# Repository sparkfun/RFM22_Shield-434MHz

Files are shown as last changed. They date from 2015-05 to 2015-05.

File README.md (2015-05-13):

SparkFun RFM22 Shield - 434MHz
========================================

SparkFun RFM22 Shield - 434MHz

[*SparkFun RFM22 Shield - 434MHz (DEV-11018)*](https://www.sparkfun.com/products/11018)

The RFM22 Shield connects the RFM22 module to the appropriate lines on the Arduino. 
By using the RF22 Library, you can send and receive messages via standard 4-wire SPI. 
The library includes command structures for setting up anything from simple non-addressed point-to-point communication to fully addressed networks of clients and routers. 
The shield also provides a through-hole antenna connection for hooking up a basic wire antenna.

Repository Contents
-------------------

* **/Firmware** - Example code 
* **/Hardware** - Eagle design files (.brd, .sch)
* **/Libraries** - Libraries for use with the <PRODUCT NAME>
* **/Production** - Production panel files (.brd)

Documentation
--------------
* **[Library](https://github.com/sparkfun/SparkFun_RadioHead_Arduino_Library)** - Arduino library for the RFM22 Shield.
* **[Hookup Guide](https://www.sparkfun.com/tutorials/381)** - Basic hookup guide for the RFM22 Shield.
* **[SparkFun Fritzing repo](https://github.com/sparkfun/Fritzing_Parts)** - Fritzing diagrams for SparkFun products.
* **[SparkFun 3D Model repo](https://github.com/sparkfun/3D_Models)** - 3D models of SparkFun products. 

License Information
-------------------
This product is _**open source**_! 

The **hardware** is released under [Creative Commons ShareAlike 4.0 International](https://creativecommons.org/licenses/by-sa/4.0/).

Please use, reuse, and modify these files as you see fit. Please maintain attribution to SparkFun Electronics and release anything derivative under the same license.

Distributed as-is; no warranty is given.

- Your friends at SparkFun.

_The library is the SparkFun fork of the RadioHead library by Mike McCauley. The original library can be found here: http://www.airspayce.com/mikem/arduino/RadioHead/_

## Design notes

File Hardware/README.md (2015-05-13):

SparkFun <PRODUCT NAME> Design Files
=====================================

The .sch and .brd files hare are Eagle CAD schematic and PCB design files from SparkFun Electronics.
A freeware version of Eagle can be found [here](http://www.cadsoftusa.com/download-eagle/freeware/). 

License
---------
This product is open source! 
The hardware is released under [Creative Commons ShareAlike 4.0 International](https://creativecommons.org/licenses/by-sa/4.0/).

Please use, reuse, and modify these files as you see fit. Please maintain attribution to SparkFun Electronics and release anything derivative under the same license.

Distributed as-is; no warranty is given.

- Your friends at SparkFun.

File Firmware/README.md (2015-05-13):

SparkFun RFM22 Shield Firmware
===================================

* **Receive_Example** - Arduino examples for receiving
* **Transmit_Example** - Arduino examples for transmitting

Firmware Notes:
------------------
This code was used to  test communication between two RFM22 modules. WinAVR (AVRDude) was used to compile and write the code.  Makefiles are set up for serial programming - check out this tutorial for more info: http://www.sparkfun.com/commerce/tutorial_info.php?tutorials_id=142.

In my testing, I used two 3.3V Arduino Pro's (ATmega328), one programmed with the Receive code and one with the Transmit. Data is transmitted in 17-byte packets (16 data, 1 checksum). All of the configuration fuctions were derived from the examples posted on HopeRF's product page:
Transmit Demo: http://www.hoperf.com/upfile/RFM22_transmit_DEMO.pdf
Receive Demo: http://www.hoperf.com/upfile/RFM22_receive_DEMO.pdf

In testing, with a 17cm wire attached to the ANT pin, I got the modules to transmit about 150ft away from eachother, down a hallway. YMMV. I'd love to hear if you got it further!

There are a number of ways to configure and use these modules, and this example is by no means the best or only way to do so. I encourage you to try fiddling with the settings to tune the RFM22 for best operation with your project.

All this code is released under the Creative Commons Share-alike v3.0 license. Feel free to use it commercially or otherwise. If you have any adjustments to make to the code, I'd love to hear about them! Drop me an email (jim@sparkfun.com).

Cheers!
-Jim

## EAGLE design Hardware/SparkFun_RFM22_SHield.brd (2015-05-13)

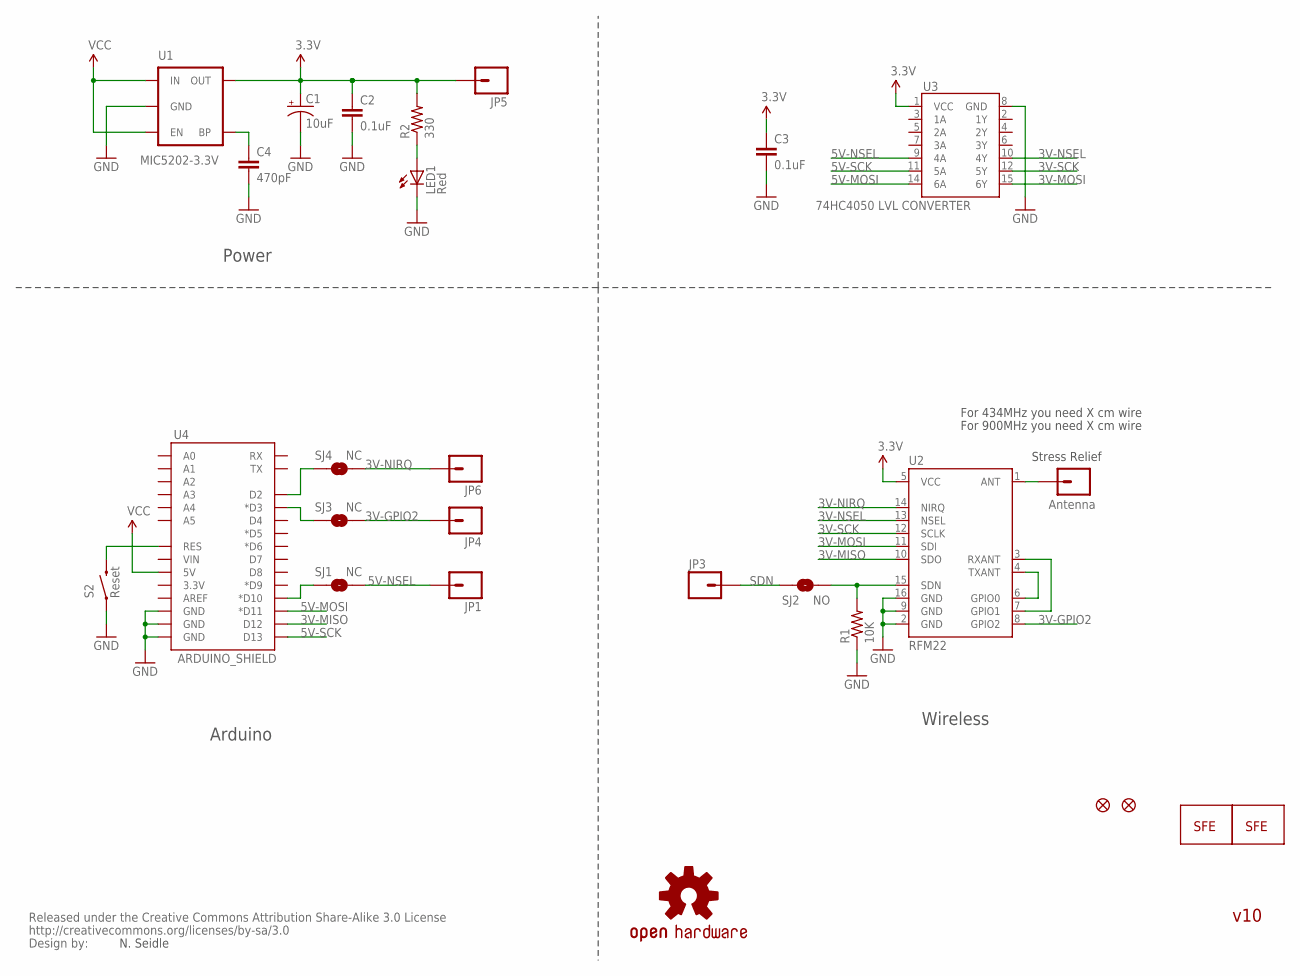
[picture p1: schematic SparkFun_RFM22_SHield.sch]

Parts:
C1: 10uF; EIA3216
C2, C3: 0.1uF; 0402-CAP
C4: 470pF; 0402-CAP
JP1, JP3, JP4, JP5, JP6: M01PTH; 1X01
JP2: Antenna; 1X01
JP7, JP8: FIDUCIALUFIDUCIAL; MICRO-FIDUCIAL
LED1: Red; LED-0603
R1: 10K; 0402-RES
R2: 330; 0402-RES
S2: Reset; TACTILE_SWITCH_SMD
SJ1, SJ3, SJ4: NC; SJ_2S-TRACE
SJ2: NO; SJ_2S-NO
U1: MIC5202-3.3V; SOT23-5
U2: RFM22; RFM22-XXX-S2
U3: 74HC4050 LVL CONVERTER; SO016
U4: ARDUINO_SHIELD; DUEMILANOVE_SHIELD_NOHOLES
U$1: OSHW-LOGOS; OSHW-LOGO-S
U$3: CREATIVE_COMMONS
U$7, U$8: LOGO-SFENEW; SFE-NEW-WEBLOGO

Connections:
3.3V: C1.A (+), C2.1, C3.1, JP5.1, R2.2, U1.5 (OUT), U2.5 (VCC), U3.1 (VCC)
3V-GPIO2: JP4.1, SJ3.2, U2.8 (GPIO2)
3V-MISO: U2.10 (SDO), U4.D12
3V-MOSI: U2.11 (SDI), U3.15 (6Y)
3V-NIRQ: JP6.1, SJ4.2, U2.14 (NIRQ)
3V-NSEL: U2.13 (NSEL), U3.10 (4Y)
3V-SCK: U2.12 (SCLK), U3.12 (5Y)
5V-MOSI: U3.14 (6A), U4.D11 (*D11)
5V-NSEL: JP1.1, SJ1.2, U3.9 (4A)
5V-SCK: U3.11 (5A), U4.D13
ARST: S2.3 (2), U4.RES
GND: C1.C (-), C2.2, C3.2, C4.2, LED1.C, R1.1, S2.1, U1.2 (GND), U2.2 (GND), U2.9 (GND), U2.16 (GND), U3.8 (GND), U4.GND@0 (GND), U4.GND@1 (GND), U4.GND@2 (GND)
unnamed: JP2.1, U2.1 (ANT)
unnamed: SJ1.1, U4.D10 (*D10)
unnamed: U2.4 (TXANT), U2.6 (GPIO0)
unnamed: U2.3 (RXANT), U2.7 (GPIO1)
unnamed: SJ3.1, U4.D3 (*D3)
unnamed: LED1.A, R2.1
unnamed: SJ4.1, U4.D2
unnamed: C4.1, U1.4 (BP)
SDN: JP3.1, SJ2.1
SDN2: R1.2, SJ2.2, U2.15 (SDN)
VCC: U1.1 (IN), U1.3 (EN), U4.5V

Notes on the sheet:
N. Seidle
Power
Arduino
Stress Relief
For 434MHz you need X cm wire
For 900MHz you need X cm wire
Wireless
v10

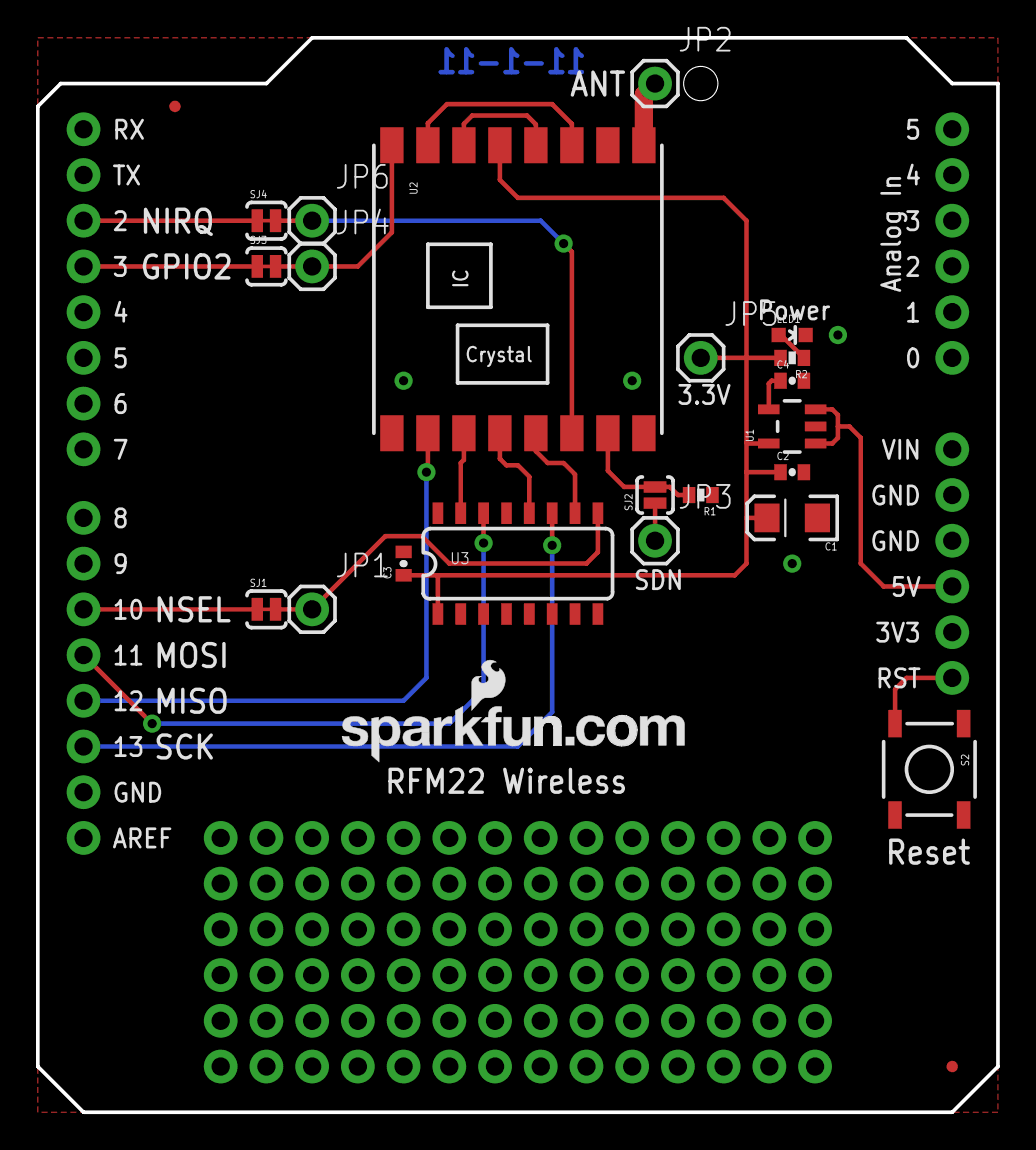
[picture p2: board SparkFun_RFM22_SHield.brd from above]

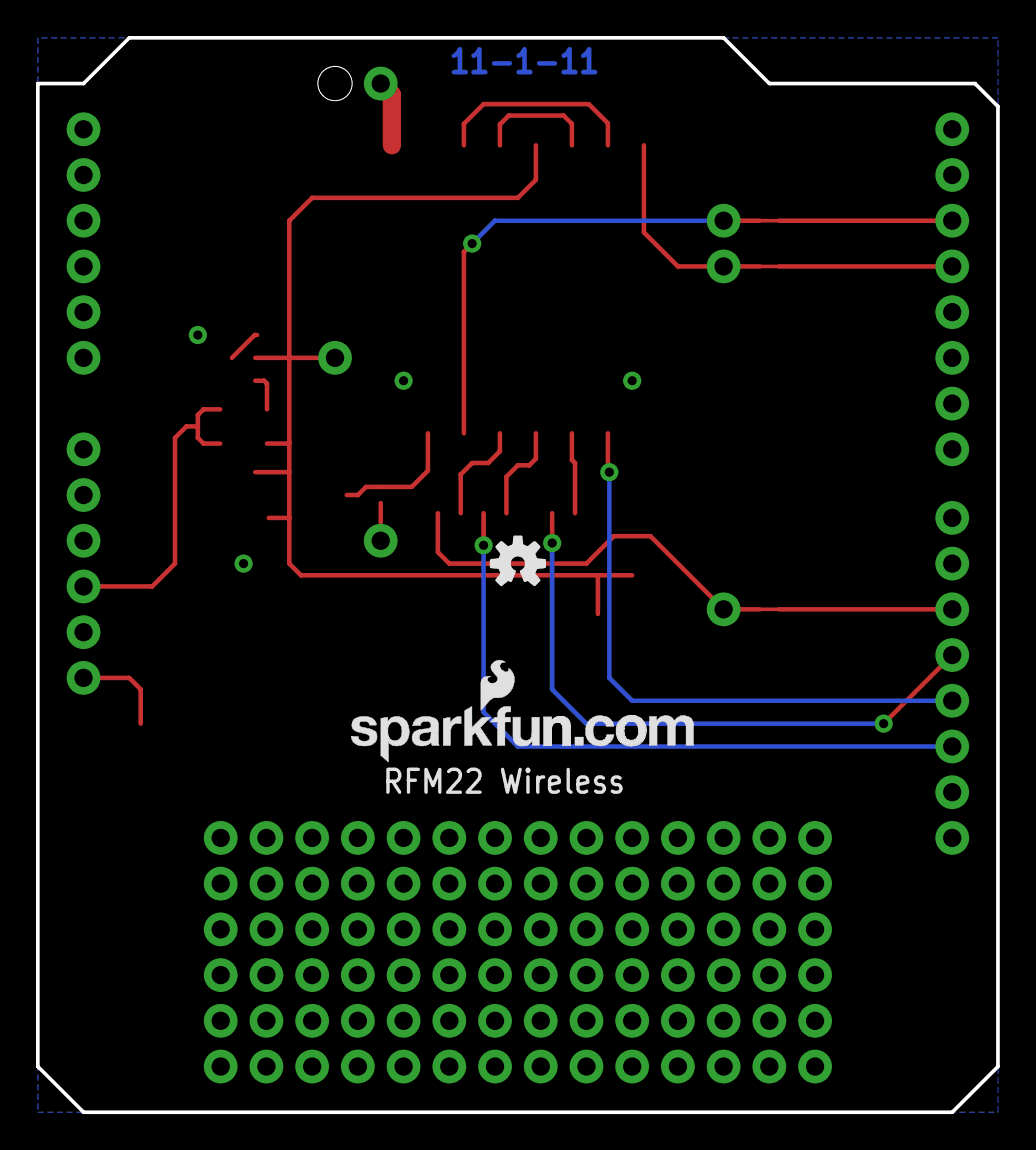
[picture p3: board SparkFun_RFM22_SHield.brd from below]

Board: 2 copper layers, 53.3 x 59.7 mm, 28 parts (2 on the bottom side), 23 nets.

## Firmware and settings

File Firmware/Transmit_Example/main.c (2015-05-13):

/*
    Created on: Mar. 30, 2010
	Under project: RFM22
	Author: Jim Lindblom
	RFM22 Transmit Example
	
	Hardware: Arduino Pro (ATmega328) running at 8Mhz, 3.3V
	Wiring:
	RFM22 BOB	|	Arduino Pro
	----------------------------
		GND		|	GND
		3.3V	|	3.3V
		GPIO0	|	NC
		GPIO1	|	NC
		GPIO2	|	NC
		RXANT	|	PD6 (D6)
		TXANT	|	PD5 (D5)
		IRQ		|	PD4 (D4)
		CSN		|	PB0 (D8)
		SCK		|	PB4 (D13)
		SDI		|	PB2 (D11)
		SDO		|	PB3 (D12)
		
	Antenna is a 17cm piece of wire sticking straight up into the air.
*/

//======================//
//======================//
#include <avr/io.h>
#include <stdio.h>
#include "RFM22.h"
//======================//
//======================//

#define sbi(var, mask)   ((var) |= (uint8_t)(1 << mask))
#define cbi(var, mask)   ((var) &= (uint8_t)~(1 << mask))

//======================//
//Arduino Pro Specific Defines
#define LED 5

//RFM22 Defines
#define CS 0 //pin for chip select
#define NIRQ 4
#define TXANT 5	// PD5
#define RXANT 6	// PD6

//======================//
//======================//

void ioinit(void);
void delay_ms(uint16_t x);
void delay_us(uint16_t x);

//======================//
//======================//

static int uart_putchar(char c, FILE *stream);
uint8_t uart_getchar(void);
static FILE mystdout = FDEV_SETUP_STREAM(uart_putchar, NULL, _FDEV_SETUP_WRITE);

//======================//
//======================//

void init_SPI(void);
void init_RFM22(void);
void to_tx_mode(void);
void checkINT(void);
void get_packet(void);
void txdata(char data);
char rxdata(void);
char read(uint8_t address);
void write(uint8_t address, char data);

//======================//
//Global Variables
unsigned char tx_buf[17] = {0x30, 0x31, 0x32, 0x33, 0x34, 0x35, 0x36, 0x37, 0x38, 0x39, 0x3A, 0x3B, 0x3C, 0x3D, 0x3E, 0x3F, 0x78};

int main(void)
{
	char temp, inkey;
	unsigned char i;

	ioinit();
	init_SPI();
	sbi(PORTB,CS);
	printf("/n/n********RFM22 Communication Test********\n");

	//====================//
	//Communications Test
	
	temp = read(DTYPE);
	temp = read(DVERS);
	temp = read(INTEN1);
	temp = read(INTEN2);
	temp = read(OMFC1);
	temp = read(OMFC2);
	
	printf("*****************************************\n\n");
	
	init_RFM22();	// Initialize all RFM22 registers
	to_tx_mode();	// Send test packet	'0123456789:;<=>?"
	
	/*// This exampes sends '0123456789:;<=>?' once a second
	while(1)
	{
		to_tx_mode();
		printf("Transmit Done\n");
		delay_ms(1000);
	}
	*/
	
	// This example allows you to enter a 16-byte packet to send
	printf("Entering TX Mode...Give me a 16-byte packet\n\n");
	while(1)
	{
		
		get_packet();
		printf("Transmitting: ");
		for (i=0; i<17; i++)
			printf("%c", tx_buf[i]);
		printf("\n");
		to_tx_mode();
		printf("Transmit done...Press any key to transmit again\n\n");
	}
	
	/*
	// This example sends a 'beep' to the terminal every second
	// You'll love it...
	int count = 0;
	unsigned char chksum;
	
	for (i=0; i<15; i++)
		tx_buf[i] = 0x07;
	tx_buf[15] = 0x31;
	
	chksum = 0;
	for(i=0; i<16; i++)
		chksum += tx_buf[i];
	
	tx_buf[16] = chksum;
	printf("chksum == %x\r", tx_buf[16]);
	
	while(1)
	{
		to_tx_mode();
		delay_ms(1000);
		
		printf("Transmission Complete...%d\n", count);
		count++;
		
	}*/
}

// Initialize the RFM22 for transmitting
void init_RFM22(void)
{
	write(INTEN2, 0x00);	// Disable all interrupts
	write(OMFC1, 0x01);		// Set READY mode
	write(0x09, 0x7F);		// Cap = 12.5pF
	write(0x0A, 0x05);		// Clk output is 2MHz
	
	write(0x0B, 0xF4);		// GPIO0 is for RX data output
	write(0x0C, 0xEF);		// GPIO1 is TX/RX data CLK output
	write(0x0D, 0x00);		// GPIO2 for MCLK output
	write(0x0E, 0x00);		// GPIO port use default value
	
	write(0x0F, 0x70);		// NO ADC used
	write(0x10, 0x00);		// no ADC used
	write(0x12, 0x00);		// No temp sensor used
	write(0x13, 0x00);		// no temp sensor used
	
	write(0x70, 0x20);		// No manchester code, no data whiting, data rate < 30Kbps
	
	write(0x1C, 0x1D);		// IF filter bandwidth
	write(0x1D, 0x40);		// AFC Loop
	//write(0x1E, 0x0A);	// AFC timing
	
	write(0x20, 0xA1);		// clock recovery
	write(0x21, 0x20);		// clock recovery
	write(0x22, 0x4E);		// clock recovery
	write(0x23, 0xA5);		// clock recovery
	write(0x24, 0x00);		// clock recovery timing
	write(0x25, 0x0A);		// clock recovery timing
	
	//write(0x2A, 0x18);
	write(0x2C, 0x00);
	write(0x2D, 0x00);
	write(0x2E, 0x00);
	
	write(0x6E, 0x27);		// TX data rate 1
	write(0x6F, 0x52);		// TX data rate 0
	
	write(0x30, 0x8C);		// Data access control
	
	write(0x32, 0xFF);		// Header control
	
	write(0x33, 0x42);		// Header 3, 2, 1, 0 used for head length, fixed packet length, synchronize word length 3, 2,
	
	write(0x34, 64);		// 64 nibble = 32 byte preamble
	write(0x35, 0x20);		// 0x35 need to detect 20bit preamble
	write(0x36, 0x2D);		// synchronize word
	write(0x37, 0xD4);
	write(0x38, 0x00);
	write(0x39, 0x00);
	write(0x3A, 's');		// set tx header 3
	write(0x3B, 'o');		// set tx header 2
	write(0x3C, 'n');		// set tx header 1
	write(0x3D, 'g');		// set tx header 0
	write(0x3E, 17);		// set packet length to 17 bytes
	
	write(0x3F, 's');		// set rx header
	write(0x40, 'o');
	write(0x41, 'n');
	write(0x42, 'g');
	write(0x43, 0xFF);		// check all bits
	write(0x44, 0xFF);		// Check all bits
	write(0x45, 0xFF);		// check all bits
	write(0x46, 0xFF);		// Check all bits
	
	write(0x56, 0x01);
	
	write(0x6D, 0x07);		// Tx power to max
	
	write(0x79, 0x00);		// no frequency hopping
	write(0x7A, 0x00);		// no frequency hopping
	
	write(0x71, 0x22);		// GFSK, fd[8]=0, no invert for TX/RX data, FIFO mode, txclk-->gpio
	
	write(0x72, 0x48);		// Frequency deviation setting to 45K=72*625
	
	write(0x73, 0x00);		// No frequency offset
	write(0x74, 0x00);		// No frequency offset
	
	write(0x75, 0x53);		// frequency set to 434MHz
	write(0x76, 0x64);		// frequency set to 434MHz
	write(0x77, 0x00);		// frequency set to 434Mhz
	
	write(0x5A, 0x7F);
	write(0x59, 0x40);
	write(0x58, 0x80);
	
	write(0x6A, 0x0B);
	write(0x68, 0x04);
	write(0x1F, 0x03);
}

void to_tx_mode(void)
{
	unsigned char i;
	
	write(0x07, 0x01);	// To ready mode
	cbi(PORTD, RXANT);
	sbi(PORTD, TXANT);
	delay_ms(50);
	
	write(0x08, 0x03);	// FIFO reset
	write(0x08, 0x00);	// Clear FIFO
	
	write(0x34, 64);	// preamble = 64nibble
	write(0x3E, 17);	// packet length = 17bytes
	for (i=0; i<17; i++)
	{
		write(0x7F, tx_buf[i]);	// send payload to the FIFO
	}

	write(0x05, 0x04);	// enable packet sent interrupt
	i = read(0x03);		// Read Interrupt status1 register
	i = read(0x04);
	
	write(0x07, 9);	// Start TX
	
	while ((PIND & (1<<NIRQ)) != 0)
		; 	// need to check interrupt here
	
	write(0x07, 0x01);	// to ready mode
	
	cbi(PORTD, RXANT);	// disable all interrupts
	cbi(PORTD, TXANT);
}

void get_packet(void)
{
	unsigned char i, chksum;
	
	for(i=0; i<16; i++)
	{
		tx_buf[i] = uart_getchar();
		printf("Received %c, %d characters remaining for packet\n", tx_buf[i], 15-i);
	}
	
	chksum = 0;
	for(i=0; i<16; i++)
		chksum += tx_buf[i];
	
	tx_buf[16] = chksum;
}

void checkINT(void)
{
	if ((PIND & (1<<NIRQ)) == 0)
		printf("INT == 0\n");
	else
		printf("INT == 1\n");
}

void write(uint8_t address, char data)
{
	//write any data byte to any single address
	//adds a 0 to the MSB of the address byte (WRITE mode)
	
	address |= 0x80;

	cbi(PORTB,CS);
	delay_ms(1);
	txdata(address);
	delay_ms(1);
	txdata(data);
	delay_ms(1);
	sbi(PORTB,CS);
}

char read(uint8_t address)
{
	//returns the contents of any 1 byte register from any address
	//sets the MSB for every address byte (READ mode)

	char byte;
	
	address &= 0x7F;

	cbi(PORTB,CS);
	txdata(address);
	byte = rxdata();
	sbi(PORTB,CS);

	return byte;
}

char rxdata(void)
{
	SPDR = 0x55;
	while((SPSR&0x80) == 0x00)
		;

	return SPDR;
}

void txdata(char data)
{
	SPDR = data;
	while((SPSR&0x80) == 0x00);
}

void init_SPI(void)
{
	// enable SPI
	// make SPI master
	// SCLK idle low
	// sample data on rising edge
	// Fosc/4 is SPI frequency = 2MHz
	//SPCR |= 0b01010000;	// Fosc/4
	SPCR |= 0b01010011;		// Fosc/128
}

static int uart_putchar(char c, FILE *stream)
{
    if (c == '\n') uart_putchar('\r', stream);

    loop_until_bit_is_set(UCSR0A, UDRE0);
    UDR0 = c;

    return 0;
}

uint8_t uart_getchar(void)
{
    while( !(UCSR0A & (1<<RXC0)) );
    return(UDR0);
}


void ioinit (void)
{
    //1 = output, 0 = input
    DDRB = 0b11101111; //MISO input
    DDRC = 0b11111111; //All outputs
    DDRD = 0b11101110; //PORTD (RX on PD0), PD4 input
	stdout = &mystdout; //Required for printf init
	int MYUBRR = 103;
	UBRR0H = (MYUBRR) >> 8;
	UBRR0L = MYUBRR;
	UCSR0B = (1<<RXEN0)|(1<<TXEN0);
	UCSR0C = (3<<UCSZ00);
	UCSR0A = (1<<U2X0);

	TCCR2B = (1<<CS21);
	
	cbi(PORTD, TXANT);
	cbi(PORTD, RXANT);
}

//General short delays
void delay_ms(uint16_t x)
{
    for (; x > 0 ; x--)
        delay_us(1000);
}

//General short delays
void delay_us(uint16_t x)
{
    while(x > 256)
    {
        TIFR2 = (1<<TOV2); //Clear any interrupt flags on Timer2
        TCNT2 = 0; //256 - 125 = 131 : Preload timer 2 for x clicks. Should be 1us per click
        while( (TIFR2 & (1<<TOV2)) == 0);

        x -= 256;
    }

    TIFR2 = (1<<TOV2); //Clear any interrupt flags on Timer2
    TCNT2= 256 - x; //256 - 125 = 131 : Preload timer 2 for x clicks. Should be 1us per click
    while( (TIFR2 & (1<<TOV2)) == 0);
}

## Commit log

2015-05-13 Adding example sketches, hardware files
    [SparkFun_RFM22_SHield.brd, SparkFun_RFM22_SHield.sch]
2015-05-13 Squashed 'Libraries/Arduino/' content from commit b79a741
    git-subtree-dir: Libraries/Arduino
    git-subtree-split: b79a7412439733b9bf97c1cfd8eaaa227ad349ff
    [project.cfg]

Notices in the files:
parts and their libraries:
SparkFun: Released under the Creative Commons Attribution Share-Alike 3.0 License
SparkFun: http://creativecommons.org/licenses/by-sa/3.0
